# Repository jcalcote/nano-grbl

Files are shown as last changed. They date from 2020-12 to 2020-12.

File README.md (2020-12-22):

# nano-grbl
A KiCAD circuit board for embedding an Arduino Nano V3 and breaking out the I/O pins for GRBL.

This KiCAD project is a simple pcb allowing the embedding of an entire Arduino Nano along side minimal additional hardware for breaking out and labling I/O pins for the [GRBL](https://github.com/gnea/grbl) gcode interpreter software package.

## 3D Model

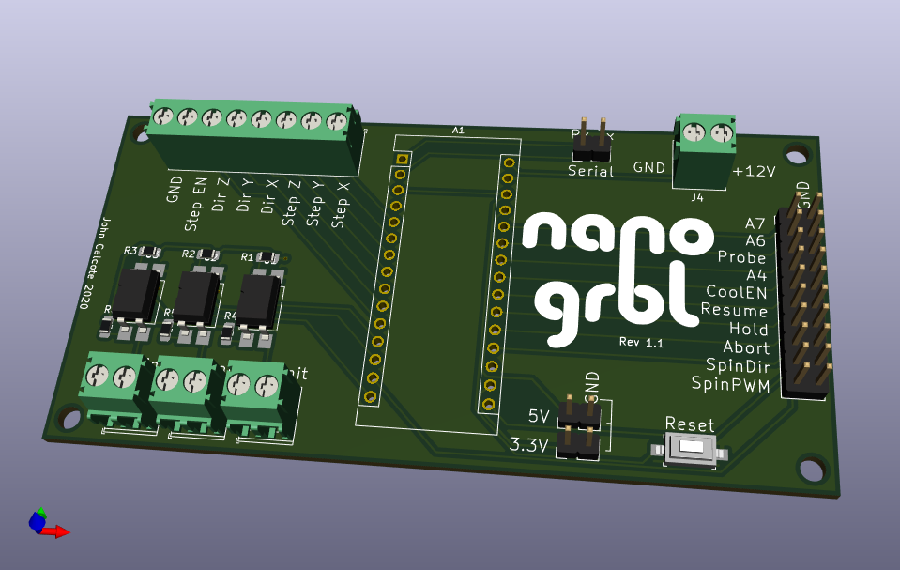
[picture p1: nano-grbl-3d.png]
nano-grbl 3d image nano-grbl 3D image


## Requirements

To use this KiCAD project, you should also clone my KiCAD parts library and add it to your clone of this project. See <https://github.com/jcalcote/KiCAD-footprints>.

## License

Creative Commons Zero 1.0 - Use at will and please enjoy.

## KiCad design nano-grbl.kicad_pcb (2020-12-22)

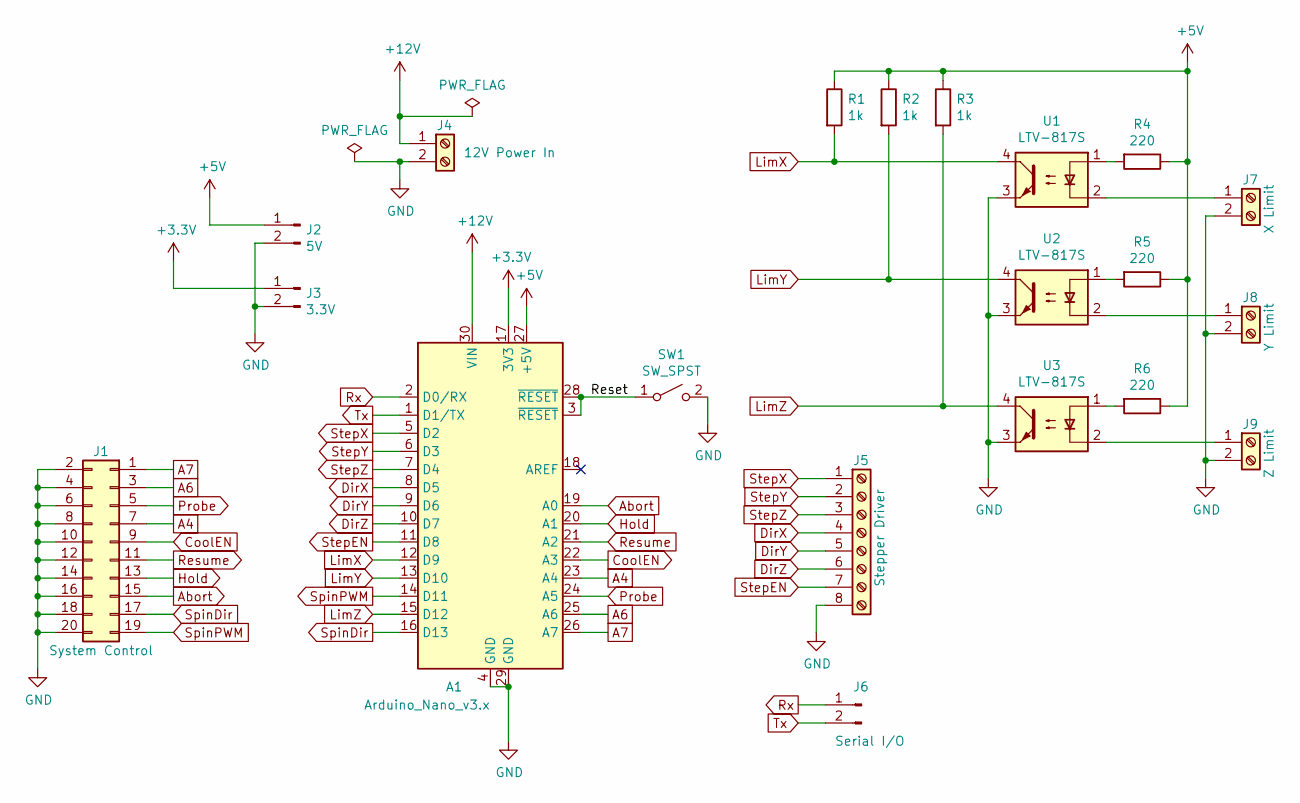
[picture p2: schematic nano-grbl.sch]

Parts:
A1: Arduino_Nano_v3.x; Arduino_Nano
J1: System Control; PinHeader_2x10_P2.54mm_Vertical
J2: 5V; PinHeader_1x02_P2.54mm_Vertical
J3: 3.3V; PinHeader_1x02_P2.54mm_Vertical
J4: 12V Power In; TerminalBlock_Phoenix_PT-1,5-2-3.5-H_1x02_P3.50mm_Horizontal
J5: Stepper Driver; TerminalBlock_Phoenix_PT-1,5-8-3.5-H_1x08_P3.50mm_Horizontal
J6: Serial I/O; PinHeader_1x02_P2.54mm_Vertical
J7: X Limit; TerminalBlock_Phoenix_PT-1,5-2-3.5-H_1x02_P3.50mm_Horizontal
J8: Y Limit; TerminalBlock_Phoenix_PT-1,5-2-3.5-H_1x02_P3.50mm_Horizontal
J9: Z Limit; TerminalBlock_Phoenix_PT-1,5-2-3.5-H_1x02_P3.50mm_Horizontal
R1, R2, R3: 1k; R_0805_2012Metric_Pad1.20x1.40mm_HandSolder
R4, R5, R6: 220; R_0805_2012Metric_Pad1.20x1.40mm_HandSolder
SW1: SW_SPST; SW_SPST_MOMENTARY_3x6_SMD
U1, U2, U3: LTV-817S; SMDIP-4_W9.53mm

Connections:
+3V3: A1.17 (3V3), J3.1
+5V: A1.27 (+5V), J2.1, R1.1, R2.1, R3.1, R4.1, R5.1, R6.1
+12V: A1.30 (VIN), J4.1
/Reset: A1.3 (~RESET), A1.28 (~RESET), SW1.1 (A)
A4: A1.23 (A4), J1.7
A6: A1.25 (A6), J1.3
A7: A1.26 (A7), J1.1
Abort: A1.19 (A0), J1.15
CoolEN: A1.22 (A3), J1.9
DirX: A1.8 (D5), J5.4
DirY: A1.9 (D6), J5.5
DirZ: A1.10 (D7), J5.6
GND: A1.4 (GND), A1.29 (GND), J1.2, J1.4, J1.6, J1.8, J1.10, J1.12, J1.14, J1.16, J1.18, J1.20, J2.2, J3.2, J4.2, J5.8, J7.2, J8.2, J9.2, SW1.2 (B), U1.3, U2.3, U3.3
Hold: A1.20 (A1), J1.13
LimX: A1.12 (D9), R1.2, U1.4
LimY: A1.13 (D10), R2.2, U2.4
LimZ: A1.15 (D12), R3.2, U3.4
unnamed: J7.1, U1.2
unnamed: J8.1, U2.2
unnamed: J9.1, U3.2
unnamed: R4.2, U1.1
unnamed: R5.2, U2.1
unnamed: R6.2, U3.1
Probe: A1.24 (A5), J1.5
Resume: A1.21 (A2), J1.11
Rx: A1.2 (D0/RX), J6.1
SpinDir: A1.16 (D13), J1.17
SpinPWM: A1.14 (D11), J1.19
StepEN: A1.11 (D8), J5.7
StepX: A1.5 (D2), J5.1
StepY: A1.6 (D3), J5.2
StepZ: A1.7 (D4), J5.3
Tx: A1.1 (D1/TX), J6.2

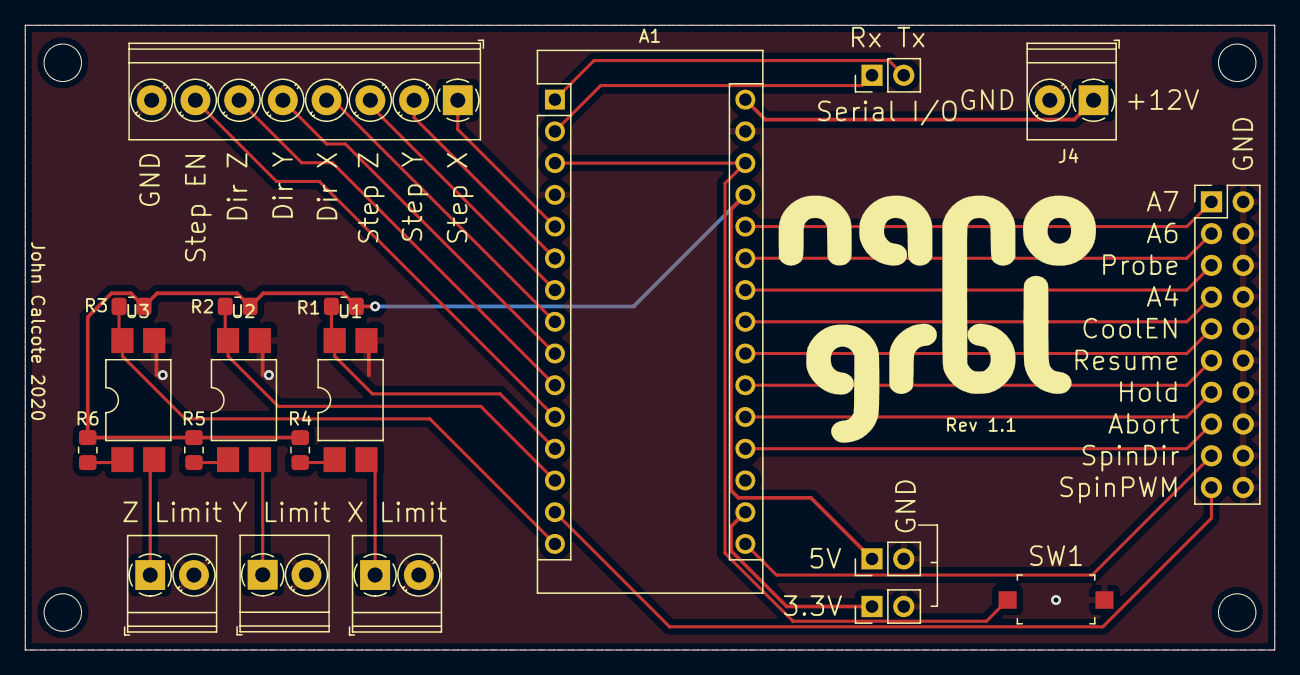
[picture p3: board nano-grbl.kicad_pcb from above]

Board: 2 copper layers, 100.0 x 50.0 mm, 20 parts (0 on the bottom side), 33 nets.

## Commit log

2020-12-21 Initial commit of board revision 1.1
    [nano-grbl.kicad_pcb, nano-grbl.sch]
2020-12-22 Update README and pcb for new footprint location.
    [nano-grbl.kicad_pcb]
